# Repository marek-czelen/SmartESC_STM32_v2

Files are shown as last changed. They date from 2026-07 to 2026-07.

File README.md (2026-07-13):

# SmartESC

**SmartESC (aka SESC) is an alternative firmware for Xiaomi M365 and Ninebot G30 controller.**



# Overview

Avantage over other Xiaomi custom firmwares :
- you can put any motor since it can detect all motor parameters and optimize them
- you can use any battery, even 20s (with hardware modifications), change the voltage divider and set the new value in the controller
- you can change the shunts values and set the new value in the controller
- you can setup the controller very easily with VESCTool and make a lot of performance/stability tests
- you can use the controller with any other device, event without any display
- soon, we hope to support multiple linked controller

Cons :
- you loose the ability to monitor M365 BMS for now (work in progress), but don't worry, you still have the voltage ;)
- you loose the ability to update firmwares through bluetooth
- for now, it needs hall sensors (no sensorless mode). [work in progress]

It can interface :
- the stock M365/G30 display
- VESCTool through VESC interface on the BMS UART (full duplex UART).

Nota : this firmware is in beta. 

You'll be able to setup and control the controller/motor from VESCTool interface with a simple USB/Serial adapter.
With any small arduino, use analog acceleration/brake throttles to control any electic moving device like escooter, gokart, electric skateboard without using the stock display.

# Download 

Download the latest build for M365 : 

# Build

Last automatic build status : 

If you want to build it manually, for an easier build, you need `git` and `docker`.

## Clone the project
`git clone https://github.com/Koxx3/SmartESC_STM32_v2.git`

## Build on Linux
Launch from terminal:

`chmod +x docker_build*; ./docker_build_m365.sh`

`chmod +x docker_build*; ./docker_build_g30.sh`

## Build on Windows
Double click :

`docker_build_m365.sh`

`docker_build_g30.sh`

# Programming

You need a ST-Link device to reprogram the M365/G3O controller.
It costs 3/4€ on Aliexpress.

Plug the st-link following this schematic :


With [STM32 ST-Link Utility](https://www.st.com/en/development-tools/stsw-link004.html), disable Re&d out protection.

Menu "Target" => "Option bytes"


# VescTool

Use [VescTool](https://vesc-project.com/vesc_tool) to setup the motor and input properties.

Use a serial USB adapter to connect the Xiaomi controller as an USB VESC :


Launch VESCTool and connect with COM port.


Launcher Motor setup wizzard.


Enter all your settings in the different windows.

Enable the keyboard control :



You're ready to test your M365 controller with your keyboard !

# ESP32 test module

M365 connections :


Use ESP32 prototype board with and ESP32-devkit-c module :


Use the code provided in the [serial-trottle-brake-esp32](/serial-trottle-brake-esp32) folder with Platform.io

# Error Code SESC (Smart ESC) in VESC Tool

Can read it in "VESC Terminal" (or others Serial Terminal)

- 0 = MC_NO_ERROR     (No error)
- 0= MC_NO_FAULTS     (No error)
- 1 = MC_FOC_DURATION (FOC rate to high)
- 2 = MC_OVER_VOLT    (Software over voltage)
- 4 = MC_UNDER_VOLT   (Software under voltage)
- 8 = MC_OVER_TEMP    (Software over temperature)
- 16 = MC_START_UP    (Startup failed)
- 32 = MC_SPEED_FDBK  (Speed feedback)
- 64 = MC_BREAK_IN    (Emergency input (Over current))
- 128 = MC_SW_ERROR

# Command available in VESCTool terminal

- help (see all available commands)
- foc_openloop [current] [erpm]  (Exemple : foc_openloop 10 500)
- ... (lot of other commands)

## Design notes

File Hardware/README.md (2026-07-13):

# Hardware Tools

Mosfets bending tool M365 to easily bend the legs of new mosfets 

Link : 
- Fusion360 https://a360.co/3qcQ0Wm
- STL [Bender legs TO220 M365 ESC] in the /hardware_tools folder

# Hardware Informations to Upgrade

Informations for Upgrade the Hardware 
- Google Sheet : https://docs.google.com/spreadsheets/d/1jOdUUpbCZVHQc2-eIezrbkNFHuf14I3zOeL0la91yoo/edit?usp=sharing

Tutorial for Simple 20S modification 

- Hardware modification : https://docs.google.com/spreadsheets/d/15NJW5ABOqHJWt1sHm2iTJhP_wqReokJQz8fKPkYVTDk/edit?usp=sharing

- Software : 

For match the Hardware and the Software you have to set VOLTAGE_DIVIDER_GAIN line 51 in the product.h at "1480" with CubeIDE

Warning
the Main voltage Regulator is limited at 90v ABSOLUT MAX, you need to select the maximum voltage protection in VESC Tool at 86~88v maximum, and be carful with the electric brake and the current when the 20S battery is full charged, i recommand to dont charge the battery at maximum voltage, something like 82-83v should be fine

you can see the road here : 

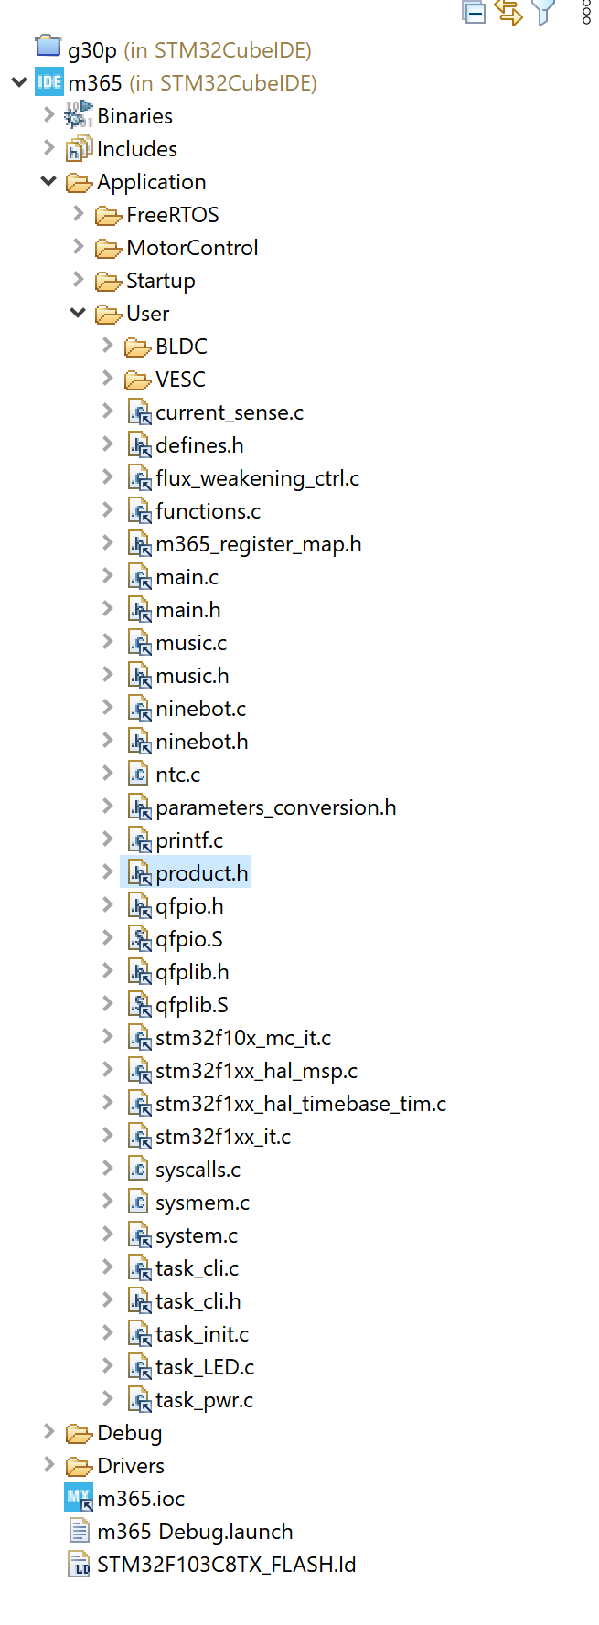
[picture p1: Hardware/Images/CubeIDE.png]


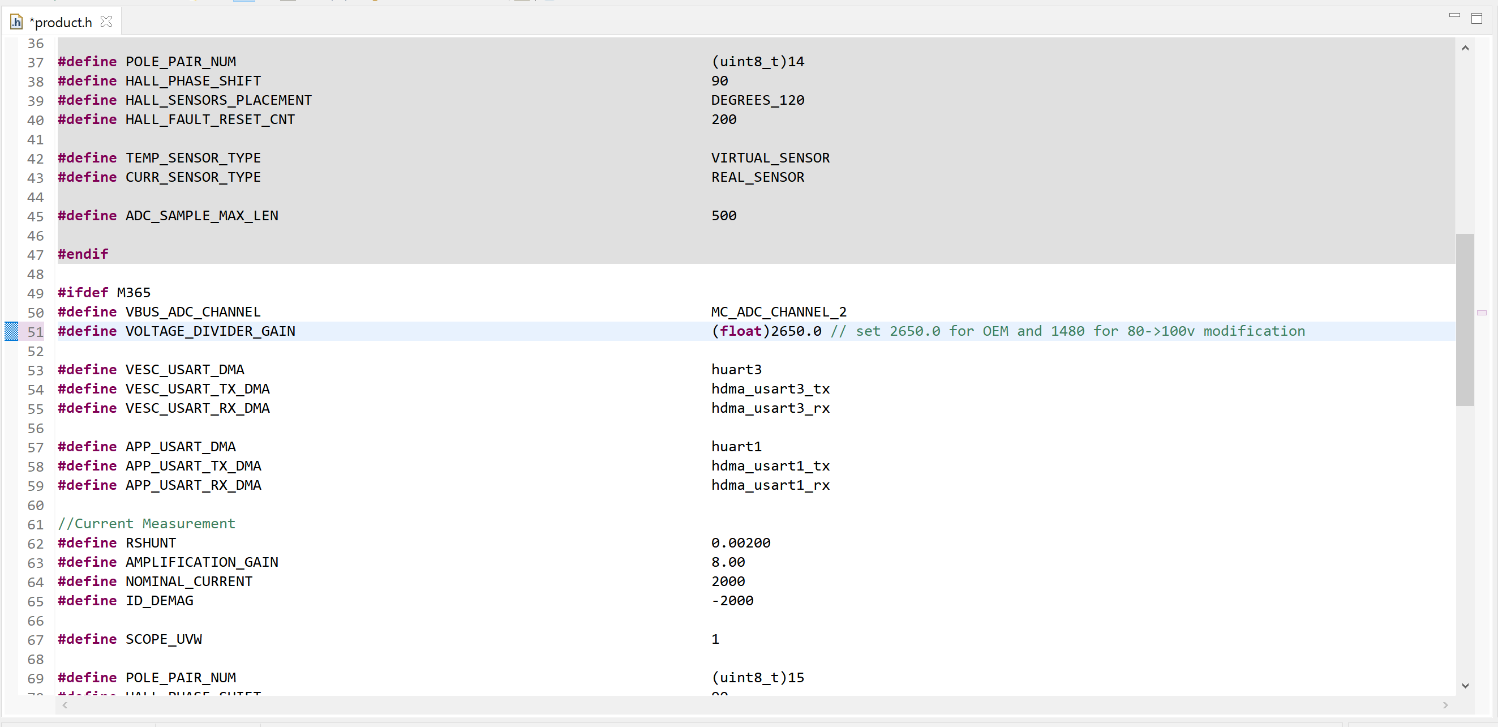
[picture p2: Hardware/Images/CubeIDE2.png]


by Foujiwara

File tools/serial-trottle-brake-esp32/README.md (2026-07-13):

# SmartESC UART Bridge — ESP32

**Mostek UART między czujnikami roweru elektrycznego a kontrolerem ESC.**

## Przeznaczenie

To oprogramowanie działa na płytce **ESP32** (PCB z projektu `bldc_driver_esp32`, bez wlutowanych driverów MOSFET). Jego zadaniem jest:

1. Odbieranie sygnałów z czujników rowerowych:
   - **PAS** (Pedal Assist Sensor) — kadencja i kierunek pedałowania
   - **Przepustnica** (throttle) — analogowa 0–3.3 V
   - **Hamulec** (brake) — sygnał cyfrowy
2. Odbieranie parametrów z **wyświetlacza S866** (protokół UART nr 2, 9600 baud)
3. Wysyłanie komend sterujących do **ESC SmartESC_STM32_v2** (protokół VESC binarny, 115200 baud)

Aplikacja **NIE steruje bezpośrednio silnikiem** — nie ma PWM na MOSFETy. Zamiast tego tłumaczy intencje rowerzysty na komendy VESC wysyłane przez UART do zewnętrznego kontrolera STM32.

## Pinout

| Funkcja | GPIO | Kierunek | Opis |
|---|---|---|---|
| `PIN_DISPLAY_EN` | 5 | OUT | Enable TXB0102 level shifter (5 V → wyświetlacz) |
| `PIN_DISPLAY_TX` | 17 | OUT | TX do wyświetlacza S866 (UART2, 9600 bd) |
| `PIN_DISPLAY_RX` | 16 | IN | RX z wyświetlacza S866 (UART2) |
| `PIN_THROTTLE` | 33 | ADC | Przepustnica 0–3.3 V (ADC1_CH5) |
| `PIN_PAS` | 22 | IN+PULLUP | Czujnik PAS (cyfrowy, impulsy) |
| `PIN_BRAKE` | 23 | IN+PULLUP | Hamulec (aktywny LOW) |
| `PIN_ESC_RX` | 4 | IN | RX z ESC (UART1, 115200 bd) |
| `PIN_ESC_TX` | 18 | OUT | TX do ESC (UART1) |

## Architektura UART

```
ESP32
├── Serial  (UART0) ── USB ── PC (debug/monitor, 115200)
├── Serial1 (UART1) ── GPIO4/18 ── ESC SmartESC_STM32_v2 (VESC protokół, 115200)
└── Serial2 (UART2) ── GPIO16/17 ── wyświetlacz S866 (protokół 2, 9600)
```

## Protokoły

### VESC (do ESC)
- Ramka: `[0x02] [len] [cmd+payload] [CRC16 hi] [CRC16 lo] [0x03]`
- CRC16: XMODEM (wielomian 0x1021)
- Używane komendy:
  - `0x04` COMM_GET_VALUES — pobranie telemetrii (V_in, I_motor, ERPM, duty, temp)
  - `0x05` COMM_SET_DUTY — ustawienie duty cycle (-1.0..1.0, int32 ×100000)
  - `0x06` COMM_SET_CURRENT — ustawienie prądu (A, int32 ×1000)

### S866 Display (z/do wyświetlacza)
- Ramka RX (wyświetlacz → ESP): 20 bajtów, checksum XOR, ~100ms interwał
- Ramka TX (ESP → wyświetlacz): 14 bajtów, checksum XOR
- Kluczowe parametry odbierane:
  - `P06` — rozmiar koła ×10 cali (bajty 7-8)
  - `P08` — limit prędkości (bajt 12)
  - `P10` — tryb sterowania: 0=PAS+throttle, 1=throttle, 2=PAS (bajt 3)
  - `P14` — limit prądu [A] (bajt 13)
  - `assist_level` — poziom wspomagania 0-9 (bajt 4, bity 0-3)

## Logika sterowania

1. **Hamulec** → natychmiast `duty=0`, wysłane do ESC
2. **P10=0** (PAS+throttle): przepustnica ma priorytet; przy braku przepustnicy → PAS
3. **P10=1** (tylko throttle): ADC mapowane liniowo na duty 0..1
4. **P10=2** (tylko PAS): kadencja pedałowania × poziom wspomagania → prędkość docelowa → regulator P → duty

Poziomy wspomagania mapowane są na prędkość docelową:
- Level 0 = off
- Level 1 = 8 km/h
- Level 2 = 15 km/h
- Level 3 = 20 km/h
- Level 4 = 25 km/h
- Level 5 = 30 km/h
- Level 6-9 = 33-45 km/h

Limit z P08 nadpisuje mapę jeśli jest niższy.

## Filtracja wejść

| Wejście | Metoda |
|---|---|
| Przepustnica (ADC) | Mediana z 8 próbek + odrzucanie outlierów (>150 ADC od mediany) |
| PAS | Timer sprzętowy 2 kHz + filtr cyfrowy (6 próbek = ~3ms debounce) |
| Hamulec | Debounce 30 ms (stan musi się utrzymać) |

## Pliki źródłowe

| Plik | Zawartość |
|---|---|
| `include/pinout.h` | Wszystkie definicje pinów GPIO, ADC, stałe czasowe |
| `include/display_s866.h` | Struktury i API protokołu wyświetlacza S866 |
| `include/vesc_proto.h` | Struktury i API protokołu VESC (ESC) |
| `src/main.cpp` | Główna pętla: setup(), loop(), filtracja, logika sterowania |
| `src/display_s866.cpp` | Implementacja protokołu S866 (odbiór ramek RX, wysyłanie TX) |
| `src/vesc_proto.cpp` | Implementacja VESC (CRC16, ramkowanie, parsowanie telemetrii) |

## Zależności

- **PlatformIO**, framework **Arduino** dla **ESP32** (espressif32)
- Brak zewnętrznych bibliotek — tylko standardowe Arduino + ESP32 SDK

## Budowanie

```bash
cd tools/serial-trottle-brake-esp32
pio run -t upload
pio device monitor
```

## Uwagi projektowe

- PCB z `bldc_driver_esp32` — NIE wlutowuj driverów IR2103 ani MOSFETów; wykorzystane jest tylko ESP32 + wejścia czujników + goldpiny UART.
- GPIO5 (DISPLAY_EN) jest pinem strap ESP32 — musi być HIGH przy boot. Kod ustawia go HIGH dopiero w `setup()`, co jest bezpieczne.
- GPIO4 i GPIO18 (ESC UART) były oryginalnie na czujniki Halla A/B — w tej aplikacji są wolne i użyte do komunikacji z ESC.
- Do programowania przez USB potrzebny jest mostek USB-UART na płytce (standardowo CP2102/CH340).

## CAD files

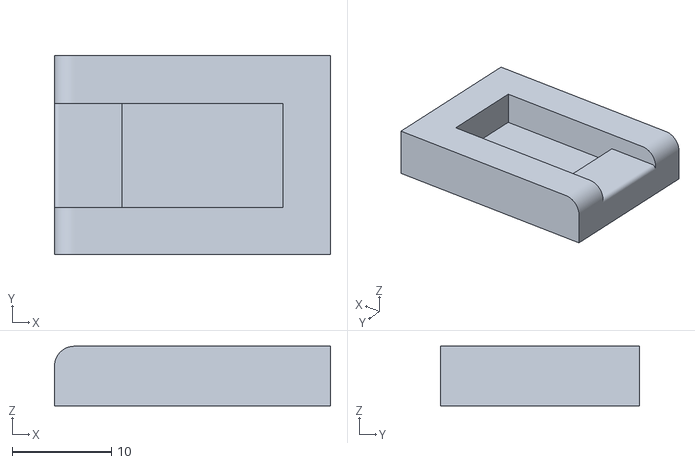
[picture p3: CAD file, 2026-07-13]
Hardware/Bender legs TO220 M365 ESC.stl
27.8 x 20.0 x 6.00

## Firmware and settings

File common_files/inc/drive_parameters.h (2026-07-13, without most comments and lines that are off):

#define __DRIVE_PARAMETERS_H
#define MAX_APPLICATION_SPEED_RPM       2500
#define MIN_APPLICATION_SPEED_RPM       0
#define MEAS_ERRORS_BEFORE_FAULTS       20
#define HALL_MEAS_ERRORS_BEFORE_FAULTS  3
#define HALL_AVERAGING_FIFO_DEPTH        12
#define HALL_MTPA  false
#define REV_PARK_ANGLE_COMPENSATION_FACTOR 0
#define PWM_FREQUENCY   16000
#define PWM_FREQ_SCALING 1
#define LOW_SIDE_SIGNALS_ENABLING        LS_PWM_TIMER
#define SW_DEADTIME_NS                   800
#define REGULATION_EXECUTION_RATE     1
#define PID_TORQUE_KP_DEFAULT         500
#define PID_TORQUE_KI_DEFAULT         300
#define PID_TORQUE_KD_DEFAULT         100
#define PID_FLUX_KP_DEFAULT           500
#define PID_FLUX_KI_DEFAULT           300
#define PID_FLUX_KD_DEFAULT           100
#define TF_KPDIV                      1024
#define TF_KIDIV                      16384
#define TF_KDDIV                      8192
#define TF_KPDIV_LOG                  LOG2(1024)
#define TF_KIDIV_LOG                  LOG2(16384)
#define TF_KDDIV_LOG                  LOG2(8192)
#define TFDIFFERENTIAL_TERM_ENABLING  DISABLE
#define SPEED_LOOP_FREQUENCY_HZ       1000
#define PID_SPEED_KP_DEFAULT          400/(SPEED_UNIT/10)
#define PID_SPEED_KI_DEFAULT          50/(SPEED_UNIT/10)
#define PID_SPEED_KD_DEFAULT          0/(SPEED_UNIT/10)
#define SP_KPDIV                      16
#define SP_KIDIV                      256
#define SP_KDDIV                      16
#define SP_KPDIV_LOG                  LOG2(16)
#define SP_KIDIV_LOG                  LOG2(256)
#define SP_KDDIV_LOG                  LOG2(16)
#define PID_SPEED_INTEGRAL_INIT_DIV 1
#define SPD_DIFFERENTIAL_TERM_ENABLING DISABLE
#define IQMAX                          4766
#define DEFAULT_CONTROL_MODE           STC_TORQUE_MODE
#define DEFAULT_TARGET_SPEED_RPM      0
#define DEFAULT_TARGET_SPEED_UNIT      (DEFAULT_TARGET_SPEED_RPM*SPEED_UNIT/_RPM)
#define DEFAULT_TORQUE_COMPONENT       0
#define DEFAULT_FLUX_COMPONENT         0
#define OV_VOLTAGE_PROT_ENABLING        ENABLE
#define UV_VOLTAGE_PROT_ENABLING        ENABLE
#define OV_VOLTAGE_THRESHOLD_V          42
#define UD_VOLTAGE_THRESHOLD_V          10
#define R_BRAKE_SWITCH_OFF_THRES_V      34
#define OV_TEMPERATURE_THRESHOLD_C      70
#define OV_TEMPERATURE_HYSTERESIS_C     5
#define HW_OV_CURRENT_PROT_BYPASS       DISABLE
#define TRANSITION_DURATION            25
#define  M1_VBUS_SAMPLING_TIME  LL_ADC_SAMPLING_CYCLE(1)
#define  M1_TEMP_SAMPLING_TIME  LL_ADC_SAMPLING_CYCLE(1)
#define ADC_SAMPLING_CYCLES (1 + SAMPLING_CYCLE_CORRECTION)
#define FW_VOLTAGE_REF                985
#define FW_KP_GAIN                    2000
#define FW_KI_GAIN                    5000
#define FW_KPDIV                      32768
#define FW_KIDIV                      32768
#define FW_KPDIV_LOG                  LOG2(32768)
#define FW_KIDIV_LOG                  LOG2(32768)
#define MTPA_ENABLING
#define SEGDIV                         595
#define ANGC                           {0,0,0,0,-55,0,-54,-54}
#define OFST                           {0,0,0,0,4,-1,4,4}

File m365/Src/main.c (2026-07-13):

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
/* Includes ------------------------------------------------------------------*/
#include "main.h"

/* USER CODE BEGIN Includes */
#include "cmsis_os.h"
#include "FreeRTOS.h"
#include "task.h"
#include "task_init.h"
#include "motorcontrol.h"
#include "conf_general.h"
#include "app.h"
#include "product.h"

/* USER CODE END Includes */

ADC_HandleTypeDef hadc1;
ADC_HandleTypeDef hadc2;
DMA_HandleTypeDef hdma_adc1;

TIM_HandleTypeDef htim1;
TIM_HandleTypeDef htim3;

UART_HandleTypeDef huart1;
UART_HandleTypeDef huart3;
DMA_HandleTypeDef hdma_usart1_tx;
DMA_HandleTypeDef hdma_usart1_rx;
DMA_HandleTypeDef hdma_usart3_rx;
DMA_HandleTypeDef hdma_usart3_tx;

/* USER CODE BEGIN PV */
/* Definitions for mediumFrequency */

/* USER CODE END PV */

void SystemClock_Config(void);
static void MX_GPIO_Init(void);
static void MX_DMA_Init(void);
static void MX_ADC1_Init(void);
static void MX_ADC2_Init(void);
static void MX_TIM1_Init(void);
static void MX_TIM3_Init(void);
static void MX_USART3_UART_Init(void);
static void MX_USART1_UART_Init(void);
static void MX_NVIC_Init(void);
/* USER CODE BEGIN PFP */
void startMediumFrequencyTask(void *argument);
extern void StartSafetyTask(void *argument);


/* USER CODE END PFP */

/**
  * @brief  The application entry point.
  * @retval int
  */
int main(void)
{
  /* MCU Configuration--------------------------------------------------------*/

  /* Reset of all peripherals, Initializes the Flash interface and the Systick. */
  HAL_Init();

  /* Configure the system clock */
  SystemClock_Config();

  /* Initialize all configured peripherals */
  MX_GPIO_Init();
  MX_DMA_Init();
  MX_ADC1_Init();
  MX_ADC2_Init();
  MX_TIM1_Init();
  MX_TIM3_Init();
  MX_USART3_UART_Init();
  MX_USART1_UART_Init();

  /* Initialize interrupts */
  MX_NVIC_Init();
  /* USER CODE BEGIN 2 */

  HAL_ADCEx_Calibration_Start(&hadc1);
  HAL_ADCEx_Calibration_Start(&hadc2);

  MX_MotorControl_Init();
  HAL_Delay(100);

  conf_general_init();


  //osKernelInitialize();

  /* USER CODE BEGIN RTOS_MUTEX */
  /* add mutexes, ... */
  HAL_GPIO_WritePin(TPS_ENA_GPIO_Port, TPS_ENA_Pin, GPIO_PIN_SET);
  /* USER CODE END RTOS_MUTEX */

  /* USER CODE BEGIN RTOS_SEMAPHORES */
  /* add semaphores, ... */
  /* USER CODE END RTOS_SEMAPHORES */

  /* USER CODE BEGIN RTOS_TIMERS */
  /* start timers, add new ones, ... */
  /* USER CODE END RTOS_TIMERS */

  /* USER CODE BEGIN RTOS_QUEUES */
  /* add queues, ... */
  /* USER CODE END RTOS_QUEUES */

  /* Create the thread(s) */
  /* USER CODE BEGIN RTOS_THREADS */
  /* add threads, ... */
  TaskHandle_t mediumFrequencyHandle;

  TaskHandle_t safetyHandle;

  xTaskCreate(startMediumFrequencyTask, "medTSK", 128, NULL, PRIO_NORMAL, &mediumFrequencyHandle);
  xTaskCreate(StartSafetyTask, "safety", 128, NULL, PRIO_HIGHER, &safetyHandle);


  task_init(); //bring up user tasks
  HAL_GPIO_WritePin(TPS_ENA_GPIO_Port, TPS_ENA_Pin, GPIO_PIN_SET);

  /* USER CODE END RTOS_THREADS */

  /* USER CODE BEGIN RTOS_EVENTS */
  /* add events, ... */
  /* USER CODE END RTOS_EVENTS */

  /* Start scheduler */
  vTaskStartScheduler();

  /* We should never ge*/

  /* USER CODE END 2 */

  /* Infinite loop */
  /* USER CODE BEGIN WHILE */
  vTaskSwitchContext();
  while (1)
  {
    /* USER CODE END WHILE */

    /* USER CODE BEGIN 3 */
  }
  /* USER CODE END 3 */
}

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
/* USER CODE BEGIN 4 */
/* USER CODE BEGIN Header_startMediumFrequencyTask */
/**
  * @brief  Function implementing the mediumFrequency thread.
  * @param  argument: Not used
  * @retval None
  */
/* USER CODE END Header_startMediumFrequencyTask */


/* USER CODE END 4 */

/**
  * @brief  Period elapsed callback in non blocking mode
  * @note   This function is called  when TIM4 interrupt took place, inside
  * HAL_TIM_IRQHandler(). It makes a direct call to HAL_IncTick() to increment
  * a global variable "uwTick" used as application time base.
  * @param  htim : TIM handle
  * @retval None
  */
void HAL_TIM_PeriodElapsedCallback(TIM_HandleTypeDef *htim)
{
  if (htim->Instance == TIM4) {
    HAL_IncTick();
  }
}

/**
  * @brief  This function is executed in case of error occurrence.
  * @retval None
  */
void Error_Handler(void)
{
  /* USER CODE BEGIN Error_Handler_Debug */
  /* User can add his own implementation to report the HAL error return state */
  __disable_irq();
  while (1)
  {
  }
  /* USER CODE END Error_Handler_Debug */
}

#ifdef  USE_FULL_ASSERT
/**
  * @brief  Reports the name of the source file and the source line number
  *         where the assert_param error has occurred.
  * @param  file: pointer to the source file name
  * @param  line: assert_param error line source number
  * @retval None
  */
void assert_failed(uint8_t *file, uint32_t line)
{
  /* USER CODE BEGIN 6 */
  /* User can add his own implementation to report the file name and line number,
     ex: printf("Wrong parameters value: file %s on line %d\r\n", file, line) */
  /* USER CODE END 6 */
}
#endif /* USE_FULL_ASSERT */

/************************ (C) COPYRIGHT STMicroelectronics *****END OF FILE****/

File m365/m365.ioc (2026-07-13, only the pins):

Mcu.UserName=STM32F103C8Tx
PA0-WKUP.GPIO_Label=M1_TEMPERATURE
PA0-WKUP.Signal=ADCx_IN0
PA10.GPIO_Label=M1_PWM_WH
PA10.Signal=S_TIM1_CH3
PA13.Signal=SYS_JTMS-SWDIO
PA14.Signal=SYS_JTCK-SWCLK
PA15.GPIO_Label=BRAKE_LIGHT
PA15.Signal=GPIO_Output
PA2.GPIO_Label=M1_BUS_VOLTAGE
PA2.Signal=ADCx_IN2
PA3.GPIO_Label=M1_CURR_AMPL_U
PA3.Signal=SharedAnalog_PA3
PA4.GPIO_Label=M1_CURR_AMPL_V
PA4.Signal=SharedAnalog_PA4
PA5.GPIO_Label=M1_CURR_AMPL_W
PA5.Signal=SharedAnalog_PA5
PA6.GPIO_Label=PHASE_A_V
PA6.Signal=ADCx_IN6
PA7.GPIO_Label=PHASE_B_V
PA7.Signal=ADCx_IN7
PA8.GPIO_Label=M1_PWM_UH
PA8.Signal=S_TIM1_CH1
PA9.GPIO_Label=M1_PWM_VH
PA9.Signal=S_TIM1_CH2
PB0.GPIO_Label=M1_HALL_H3
PB0.Signal=S_TIM3_CH3
PB1.GPIO_Label=PHASE_C_V
PB1.Signal=ADCx_IN9
PB10.GPIO_Label=UART_TX
PB10.Signal=USART3_TX
PB11.GPIO_Label=UART_RX
PB11.Signal=USART3_RX
PB13.GPIO_Label=M1_PWM_UL
PB13.Signal=TIM1_CH1N
PB14.GPIO_Label=M1_PWM_VL
PB14.Signal=TIM1_CH2N
PB15.GPIO_Label=M1_PWM_WL
PB15.Signal=TIM1_CH3N
PB4.GPIO_Label=M1_HALL_H1
PB4.Signal=S_TIM3_CH1
PB5.GPIO_Label=M1_HALL_H2
PB5.Signal=S_TIM3_CH2
PB6.Signal=USART1_TX
PC14-OSC32_IN.GPIO_Label=PWR_BTN
PC14-OSC32_IN.Signal=GPIO_Input
PC15-OSC32_OUT.GPIO_Label=TPS_ENA
PC15-OSC32_OUT.Signal=GPIO_Output
PD1-OSC_OUT.GPIO_Label=LED
PD1-OSC_OUT.Signal=GPIO_Output

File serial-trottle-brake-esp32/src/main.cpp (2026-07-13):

#include <Arduino.h>
#include <VescUart.h>

#define DEBUG 1
#define SERIAL_BAUD 921600 // debug baudrate

#define BAUD_RATE_SMARTESC_XIAOMI 115200 // default baudrate of UART on SmartESC

// pin layout
#define PIN_SERIAL_ESP_TO_CNTRL 27 // TX esp32 -> RX controller
#define PIN_SERIAL_CNTRL_TO_ESP 14 // RX esp32 <- TX controller
#define PIN_IN_ABRAKE 34           // Brake
#define PIN_IN_ATHROTTLE 39        // Throttle

// send orders every 40ms
#define TIME_SEND 40

// deadband for analog input (applied to analog raw range 0-4095)
#define ANALOG_SAFETY_OFFSET 100

// analog min/max RAW value (range 0-4095)
// need to be set according to your ADC input voltage divider
// 3.3V = 4095
#define ANALOG_MIN_RAW 600
#define ANALOG_MAX_RAW 3200

// minimal ADC RAW value for initial calibration
// if adc read are higher, it use default minimal calibration
#define MINIMAL_ANALOG_VALUE 30

// Trottle
uint16_t analogValueThrottleRaw = 0;
uint16_t analogValueThrottleMinCalibRaw = 0;

// Brake
uint16_t analogValueBrakeRaw = 0;
uint16_t analogValueBrakeMinCalibRaw = 0;

char print_buffer[500];

// Initiate VescUart class
VescUart vescCntrl;

// hardware serial declaration
HardwareSerial hwSerCntrl(1);

// last order send time
unsigned long iTimeSend = 0;

// ########################## SETUP ##########################
void setup()
{
  Serial.begin(SERIAL_BAUD);
  Serial.println("SmartESC Serial v1.0 - vesc interface");

  pinMode(PIN_IN_ATHROTTLE, INPUT);
  pinMode(PIN_IN_ABRAKE, INPUT);

  // do it twice to improve values
  uint16_t adcValue = 0;
  adcValue = analogRead(PIN_IN_ATHROTTLE);
  adcValue = analogRead(PIN_IN_ATHROTTLE);
  if (adcValue < ANALOG_MIN_RAW)
    analogValueThrottleMinCalibRaw = adcValue;
  else
    analogValueThrottleMinCalibRaw = ANALOG_MIN_RAW;

  analogValueBrakeMinCalibRaw = analogRead(PIN_IN_ABRAKE);
  analogValueBrakeMinCalibRaw = analogRead(PIN_IN_ABRAKE);
  if (adcValue < ANALOG_MIN_RAW)
    analogValueThrottleMinCalibRaw = adcValue;
  else
    analogValueThrottleMinCalibRaw = ANALOG_MIN_RAW;

  hwSerCntrl.begin(BAUD_RATE_SMARTESC_XIAOMI, SERIAL_8N1, PIN_SERIAL_CNTRL_TO_ESP, PIN_SERIAL_ESP_TO_CNTRL);

  while (!hwSerCntrl)
  {
    ;
  }

  /** Define which ports to use as UART */
  vescCntrl.setSerialPort(&hwSerCntrl);
}

// ########################## LOOP ##########################

void loop(void)
{
  unsigned long timeNow = millis();

  // Avoid delay
  if (iTimeSend > timeNow)
    return;
  iTimeSend = timeNow + TIME_SEND;

  // Compute throttle
  analogValueThrottleRaw = analogRead(PIN_IN_ATHROTTLE);
  analogValueThrottleRaw = constrain(analogValueThrottleRaw, analogValueThrottleMinCalibRaw, ANALOG_MAX_RAW);

  // Compute brake
  analogValueBrakeRaw = analogRead(PIN_IN_ABRAKE);
  analogValueBrakeRaw = constrain(analogValueBrakeRaw, analogValueBrakeMinCalibRaw, ANALOG_MAX_RAW);

  // The valueY is used to control the speed, where 127 is the middle = no current
  uint8_t value;
  if (analogValueBrakeRaw > analogValueBrakeMinCalibRaw + ANALOG_SAFETY_OFFSET)
    value = map(analogValueBrakeRaw, analogValueBrakeMinCalibRaw + ANALOG_SAFETY_OFFSET, ANALOG_MAX_RAW, 126, 0);
  else if (analogValueThrottleRaw > analogValueThrottleMinCalibRaw + ANALOG_SAFETY_OFFSET)
    value = map(analogValueThrottleRaw, analogValueThrottleMinCalibRaw + ANALOG_SAFETY_OFFSET, ANALOG_MAX_RAW, 127, 255);
  else
    value = 127;

#if DEBUG
  Serial.println("throttleRaw = " + (String)analogValueThrottleRaw + " / throttleMinCalibRaw = " + (String)analogValueThrottleMinCalibRaw +
                 " / brakeRaw = " + (String)analogValueBrakeRaw + " / brakeMinCalibRaw = " + (String)analogValueBrakeMinCalibRaw +
                 " / nunchuckValue = " + (String)value);
#endif

  // Call the function setNunchuc kValues to send the current nunchuck values to the VESC
  vescCntrl.nunchuck.valueY = value;
  vescCntrl.setNunchuckValues();
}

// ########################## END ##########################

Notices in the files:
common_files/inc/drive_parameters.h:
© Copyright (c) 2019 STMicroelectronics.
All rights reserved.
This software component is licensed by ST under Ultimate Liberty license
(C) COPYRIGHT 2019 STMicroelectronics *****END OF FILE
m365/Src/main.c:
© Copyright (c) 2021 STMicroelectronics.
